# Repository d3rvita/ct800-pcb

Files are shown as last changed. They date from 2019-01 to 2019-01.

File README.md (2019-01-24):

# CT800-PCB

In order to become familiar with KiCAD and making something useful at the same time I started this project. The goal was to develop a PCB for the CT800 to ease the build-up. The CT800 is a dedicated chess computer made by Rasmus Althoff. It is very well documented, take a look at its homepage [www.ct800.net](https://www.ct800.net "CT800 Homepage") for detailed info. 

The developed PCB consists entirely of THT components except one SMD transistor, due to better availability of 3.3V logic level devices. Soldering SMD parts isn’t easy especially packages like LQFP64 with 0.5mm pitch, therefore the Olimex board was kept in this design. The CT800 was extended by some interfaces (RS232, Bluetooth, WLAN) for future use. The power supply was amended a bit too.

CAD files of appropriate panels for housings are also included in this project. There are two versions:

* the Spartan one consists of front and back panel which are bolted to the PCB by studs
* the Classic one consists of just a front panel for the housing used by Rasmus (Axxatronic BIM1006-BLK/PG or BIM1006-GY/PG)

These panels are intended to be transparent, hence there are no holes for display and LEDs. Due to transparency there is no need for additional button labels.

## Project Data

* __CT800_PCB__ directory contains the KiCAD project including project specific libs and footprints as well gerber files for PCB production

* __CT800_PANEL__ directory contains panels (in KiCAD layout and SVG formats) for different housings

* __gen_panel_acrylic.py__ Python script for generating panel layouts from PCB layout

* __bom.txt__ lists the bill of material, mounting material for panels not included (M3x8mm / M3x25mm studs, washers, bolts...)

## Power Supply

Depending on assembly the CT800 can be powered by different sources: 

* by a 5V source on the USB-A connector 
* by power adopter or external battery on the barrel jack
	* 8-12VDC if the 7805 voltage regulator is used 
	* 4-12VDC if the Pololu S9V11F5 is used
* by internal battery if a switch is used

The USB-B connector on the Olimex board is not intended for powering the CT800 but for USB devices like a sensor chessboard. So __don’t feed the CT800 via USB-B connector.__

__Don’t provide power from multiple sources simultaneously to the CT800 in general. This could lead to side effects or even damage!__

In order to feed the CT800 by low voltage power supply down to 4VDC  (e.g. battery) equip the PCB with the Pololu S9V11F5 voltage regulator (or similar 5V buck/boost converter) instead of the 7805. In this context replacing the 1N4007 diode by a Schottky type (e.g. 1N5818, SB130) is recommended for higher efficiency.

The CT800 firmware provides voltage monitoring for four NiMH (or alkaline) cells connected in serial, in order to protect rechargeable batteries from deep discharge. This only makes sense in conjunction with the Pololu regulator. Dispense with this monitoring eases the build-up, so omit it unless you really need it. To do so, omit the voltage divider components (R2, R3 and C1), instead connect the R2 pad next to C1 to 3.3V (red wire on ct800_spartan_bottom.jpg).

A power switch is not provided on the PCB but can be connected easily to PWR and USB_SEL pads.

### Operating Without Power Switch

The CT800 is immediately powered by plugging a 5V supply to the USB-A connector or a “wide range” power source to the barrel jack (8-12VDC or 4-12VDC depending on the used 5V regulator).

If battery monitoring is active (thus the Pololu is used), the USB power has to be redirected to 5V regulator’s input via the USB_SEL jumper: disrupt the connection on top side between the upper two pads and short-circuit the lower two. Otherwise powering via USB will result in “low batteries” error message. Because of this redirection the power adopter (or battery) is directly connected to the USB power supply. __Despite the fuses, this easily lead to damage in case two power sources are used simultaneously!__ Therefore use a switch instead or dispense with battery monitoring.

### Operating With Power Switch

Without battery monitoring a 2x3 pin toggle switch is sufficient to switch between USB-A and barrel jack supply. An external battery can still be used on the barrel jack. If internal battery is desired a 1x4 rotary switch is recommended for supply selection. Wire the switch as shown in the picture below, don’t forget to disrupt the red marked traces on the PCB.

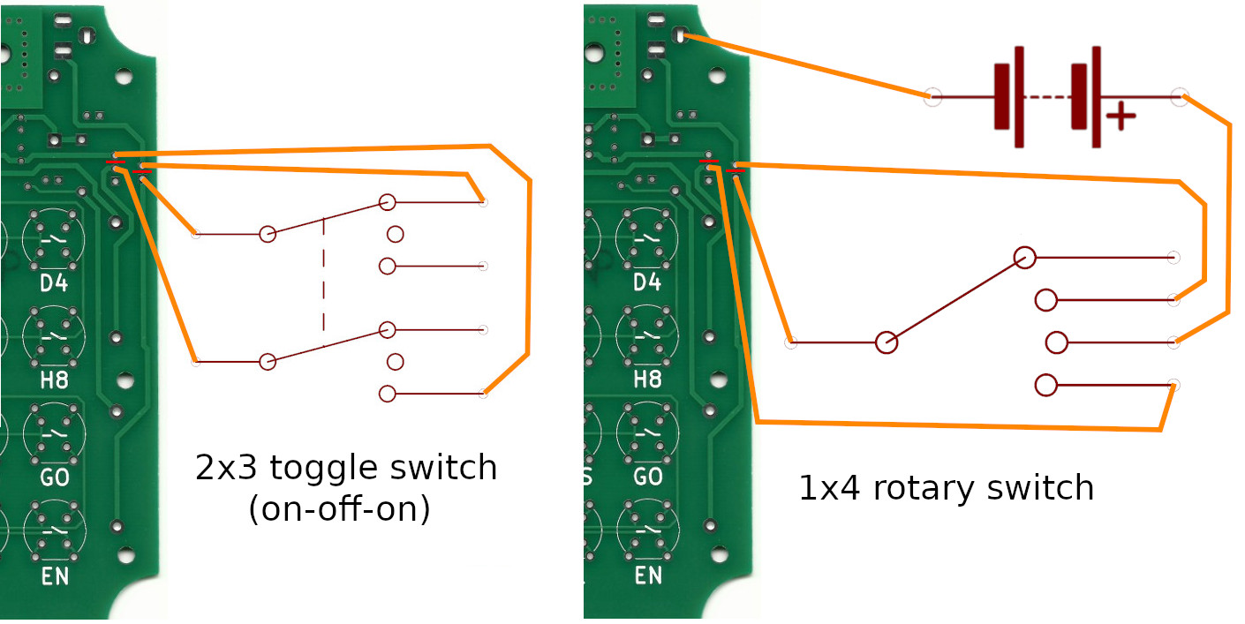
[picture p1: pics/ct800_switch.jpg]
switch


Many other switch configurations are possible. Whatever you choose, ensure power sources are never short circuit!

## PCB Assembly

Read the entire text before starting assembly. Decide what power source you want to use for feeding the CT800 and if you need a power switch or not. Since the ESP-01 is not used yet by the firmware, there is no need for equipping it. This just leads to higher current consumption. It is recommended to place the smallest components first: the SMD transistor, resistors, capacitors and then the remaining parts but the display and Olimex board. Consider the polarity of diodes, LEDs (cathode to rectangular pad = ground) and polarized capacitors. Apply heat paste to the voltage regulator(s) and screw them to the PCB before soldering. If battery monitoring is used, activate the JP3 jumper on top side. Before placing display and Olimex board check the 5V and 3.3V voltages (there are test points on the PCB). __Don’t proceed until these voltages are alright.__ Before soldering the display, screw it to the PCB and adjust the height by putting washers in between. On some displays the polarity of the back light has to be changed. On the back side of the display are jumpers for this purpose, regard the data sheet. __Don’t solder the Olimex board to the PCB, use female header instead.__ For UART communication between µC and ESP-01 the resistor R27 on the Olimex board has to be removed. In order to prevent the gold-cap to be drained in off state, the VBAT jumper on the STM32H405 board has to be disrupted. 

## Schematic

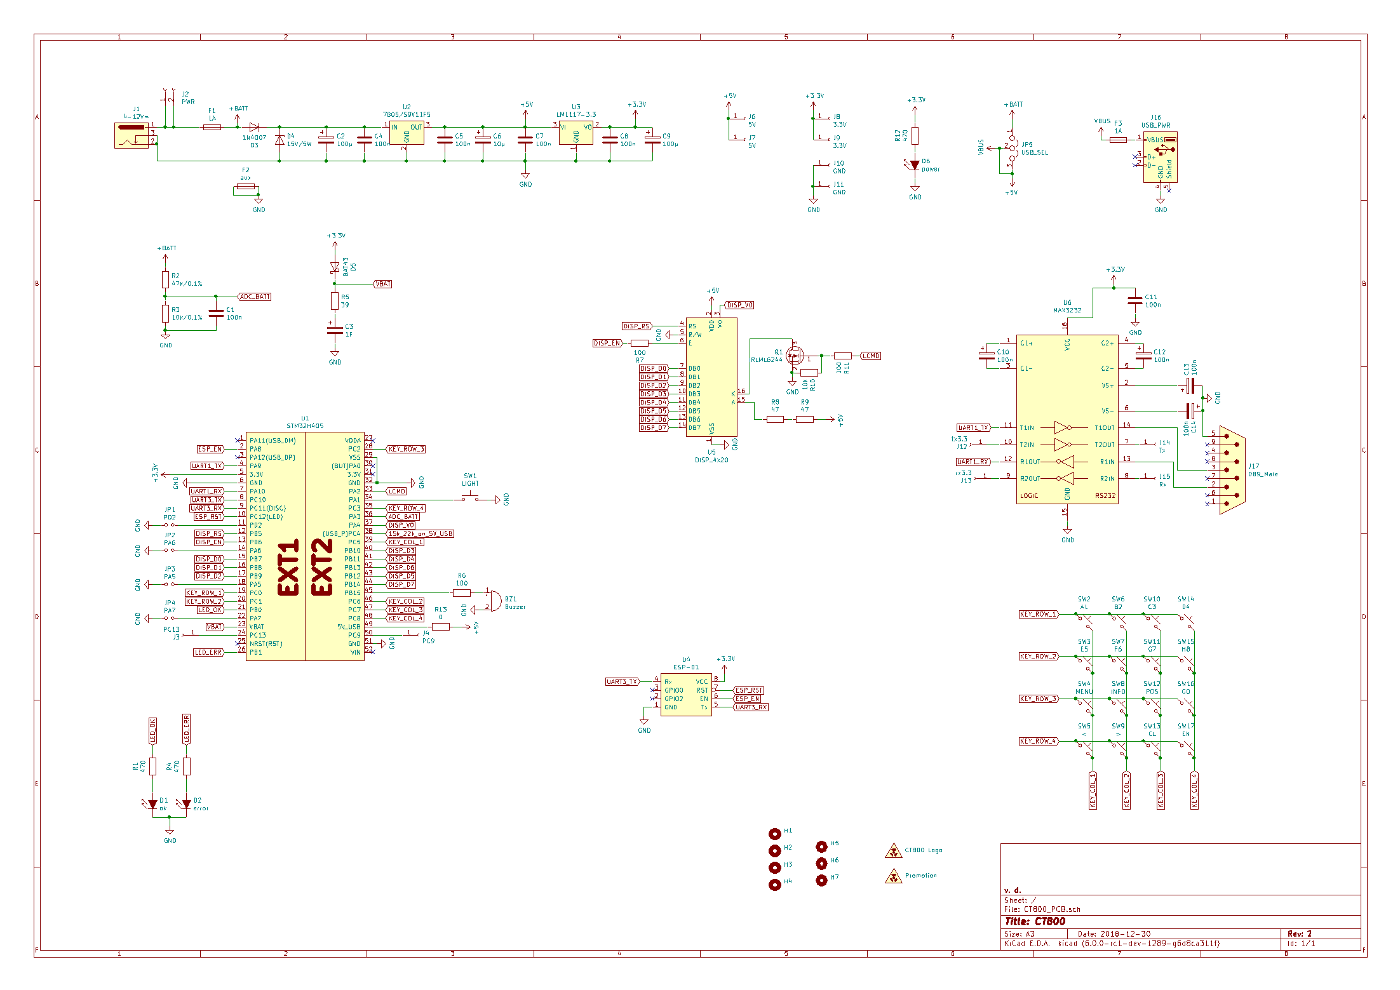
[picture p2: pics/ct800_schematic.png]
schematic


## PCB

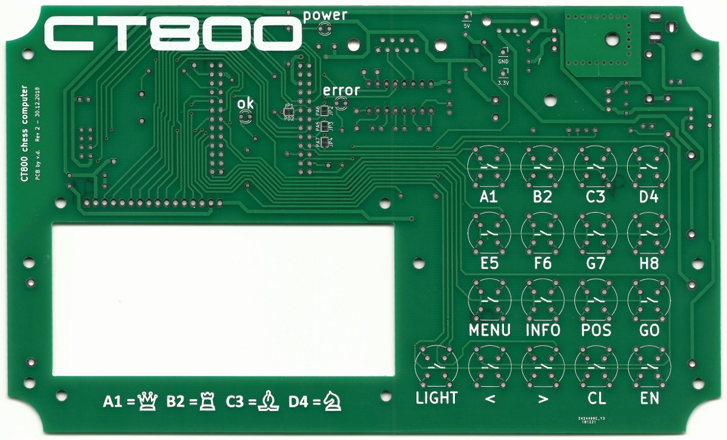
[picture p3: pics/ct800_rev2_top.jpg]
pcb_top


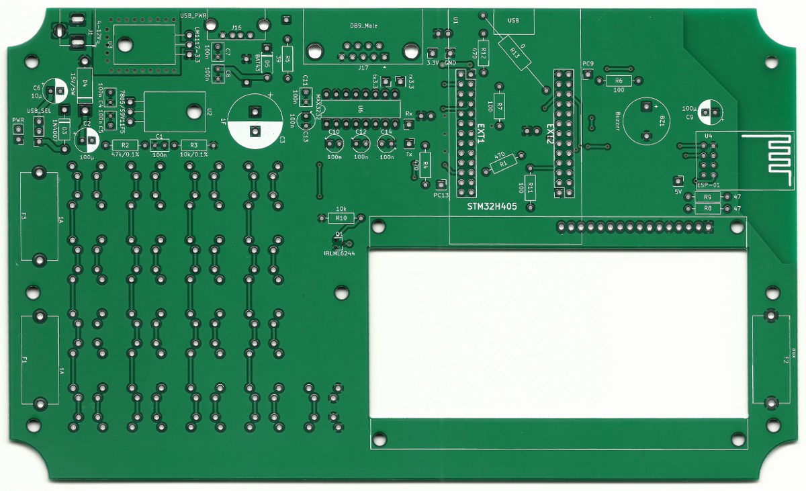
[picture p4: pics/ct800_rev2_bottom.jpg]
pcb_bottom


## Spartan Housing

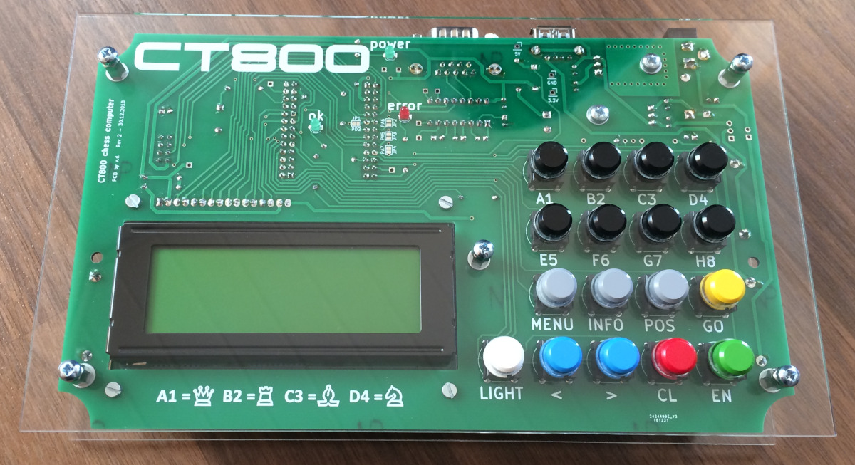
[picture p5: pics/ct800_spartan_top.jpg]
spartan_top


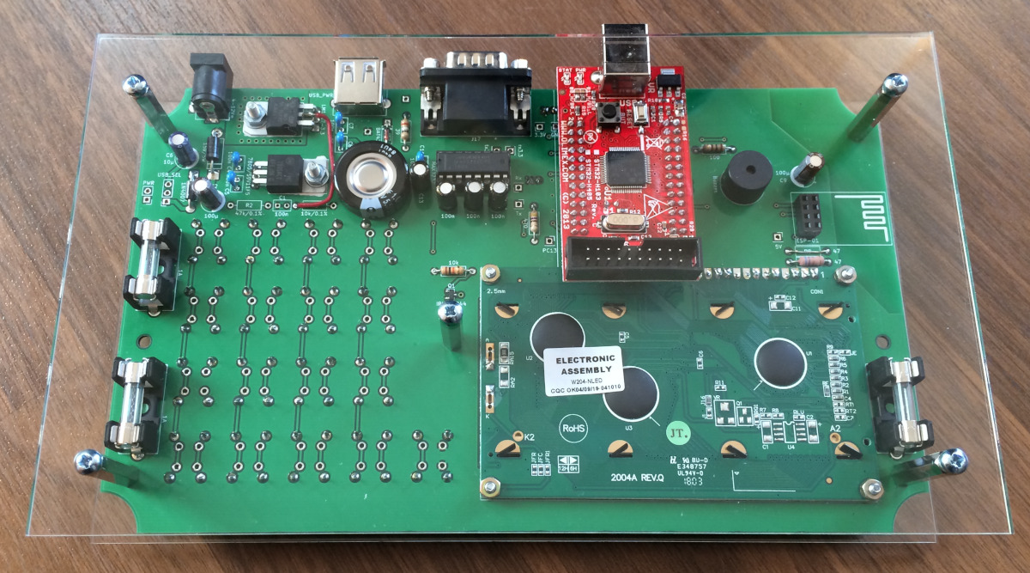
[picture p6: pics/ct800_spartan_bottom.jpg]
spartan_bottom


## Classic Housing

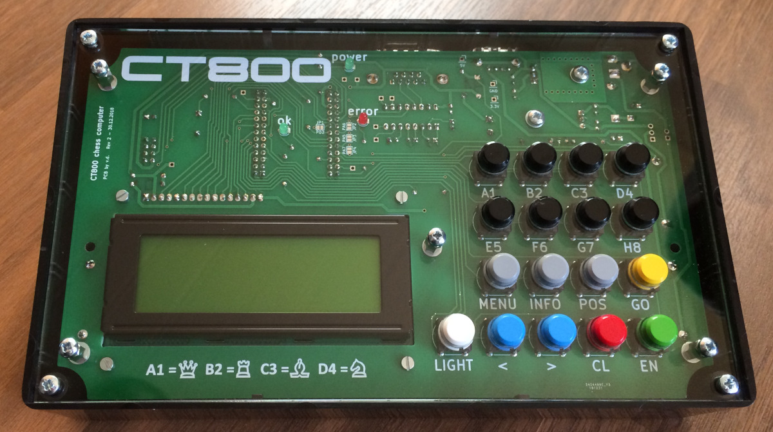
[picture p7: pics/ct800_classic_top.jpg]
classic_top

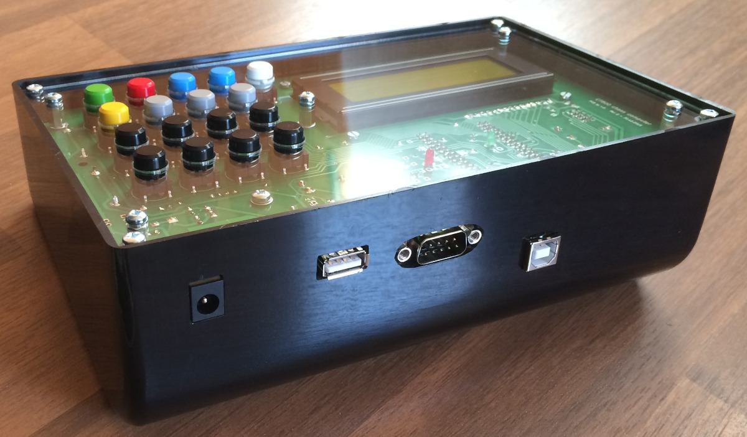
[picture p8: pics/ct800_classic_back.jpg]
classic_back


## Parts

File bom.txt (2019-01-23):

Reference		 Quantity		 Value			 Description
BZ1 				1			"Buzzer"		"Buzzer/Beeper, not a bare piezo element"
C10 C12 C13 C14 	4			"100n/16V"		"Capacitor, D4.5mm P2.50mm"
C2 C9 				2			"100µ/16V"		"Capacitor, D6.3mm P2.50mm"
C3 					1			"1F/5.5V"		"Capacitor, D14.0mm P5.00mm"
C4 C7 C5 C11 C8 C1 	6			"100n/16V"		"Capacitor, L4.6mm W3.0mm P2.50mm"
C6 					1			"10µ/16V"		"Capacitor, D6.3mm P2.50mm"
D1 					1			"ok"			"LED D3.0mm green"
D2 					1			"error"			"LED D3.0mm red"
D6 					1			"power"			"LED D3.0mm green"
D3					1			"1N4007"		"Diode DO-41, alternatively a Schottky type"
D4 					1			"15V/5W"		"Diode D_5W"
D5 					1			"BAT43"			"Diode D_A-405"
F1 F2 F3 			2			"1A/fast"		"Fuseholder P22,5mm + Fuse 5x20mm"
J1 					1			"4-12V="		"BarrelJack (5.5mm / 2.1mm, plus inside)"
J16 				1			"USB_PWR"		"USB_A Connector"
J17 				1			"DB9_Male"		"DSUB-9_Male Connector P2.77x2.84mm (Offset_9.90mm_11.32mm)"
Q1 					1			"IRLML6244"		"MOSFET SOT-23"
R10 				1			"10k"			"Resistor 0204"
R13 				1			"0"				"Wire"
R2					1			"47k/0.1%"		"Resistor 0204, for battery monitoring only"
R3					1			"10k/0.1%"		"Resistor 0204, for battery monitoring only"
R4 R1 R12 			3			"470"			"Resistor 0204"
R5 					1			"39"			"Resistor 0204"
R6 R11 R7 			3			"100"			"Resistor 0204"
R9 R8 				2			"47"			"Resistor 0204, values depending on the display back light"
SW1 - SW17			17			"~"				"Switches, MULTIMEC 3FTH9 (10.16x7.62mm) or ITT DT6 (5x5mm)"
U1 					1			"STM32H405"		"Olimex STM32H405 Board, additional: 2pc. 2x13pin female header P2.54mm"
U2 					1			"7805/S9V11F5"	"5V Voltage Regulator TO220"
U3 					1			"LM1117-3.3"	"3.3V Voltage Regulator TO220"
U4 					1			"ESP-01"		"ESP8266 board"
U5					1			"DISP_4x20"		"4x20 Display based on ST7066, additional M2.5 bolts, nuts and washers for mounting"
U6 					1			"MAX3232"		"DIP-16_W7.62mm, socket recommended"

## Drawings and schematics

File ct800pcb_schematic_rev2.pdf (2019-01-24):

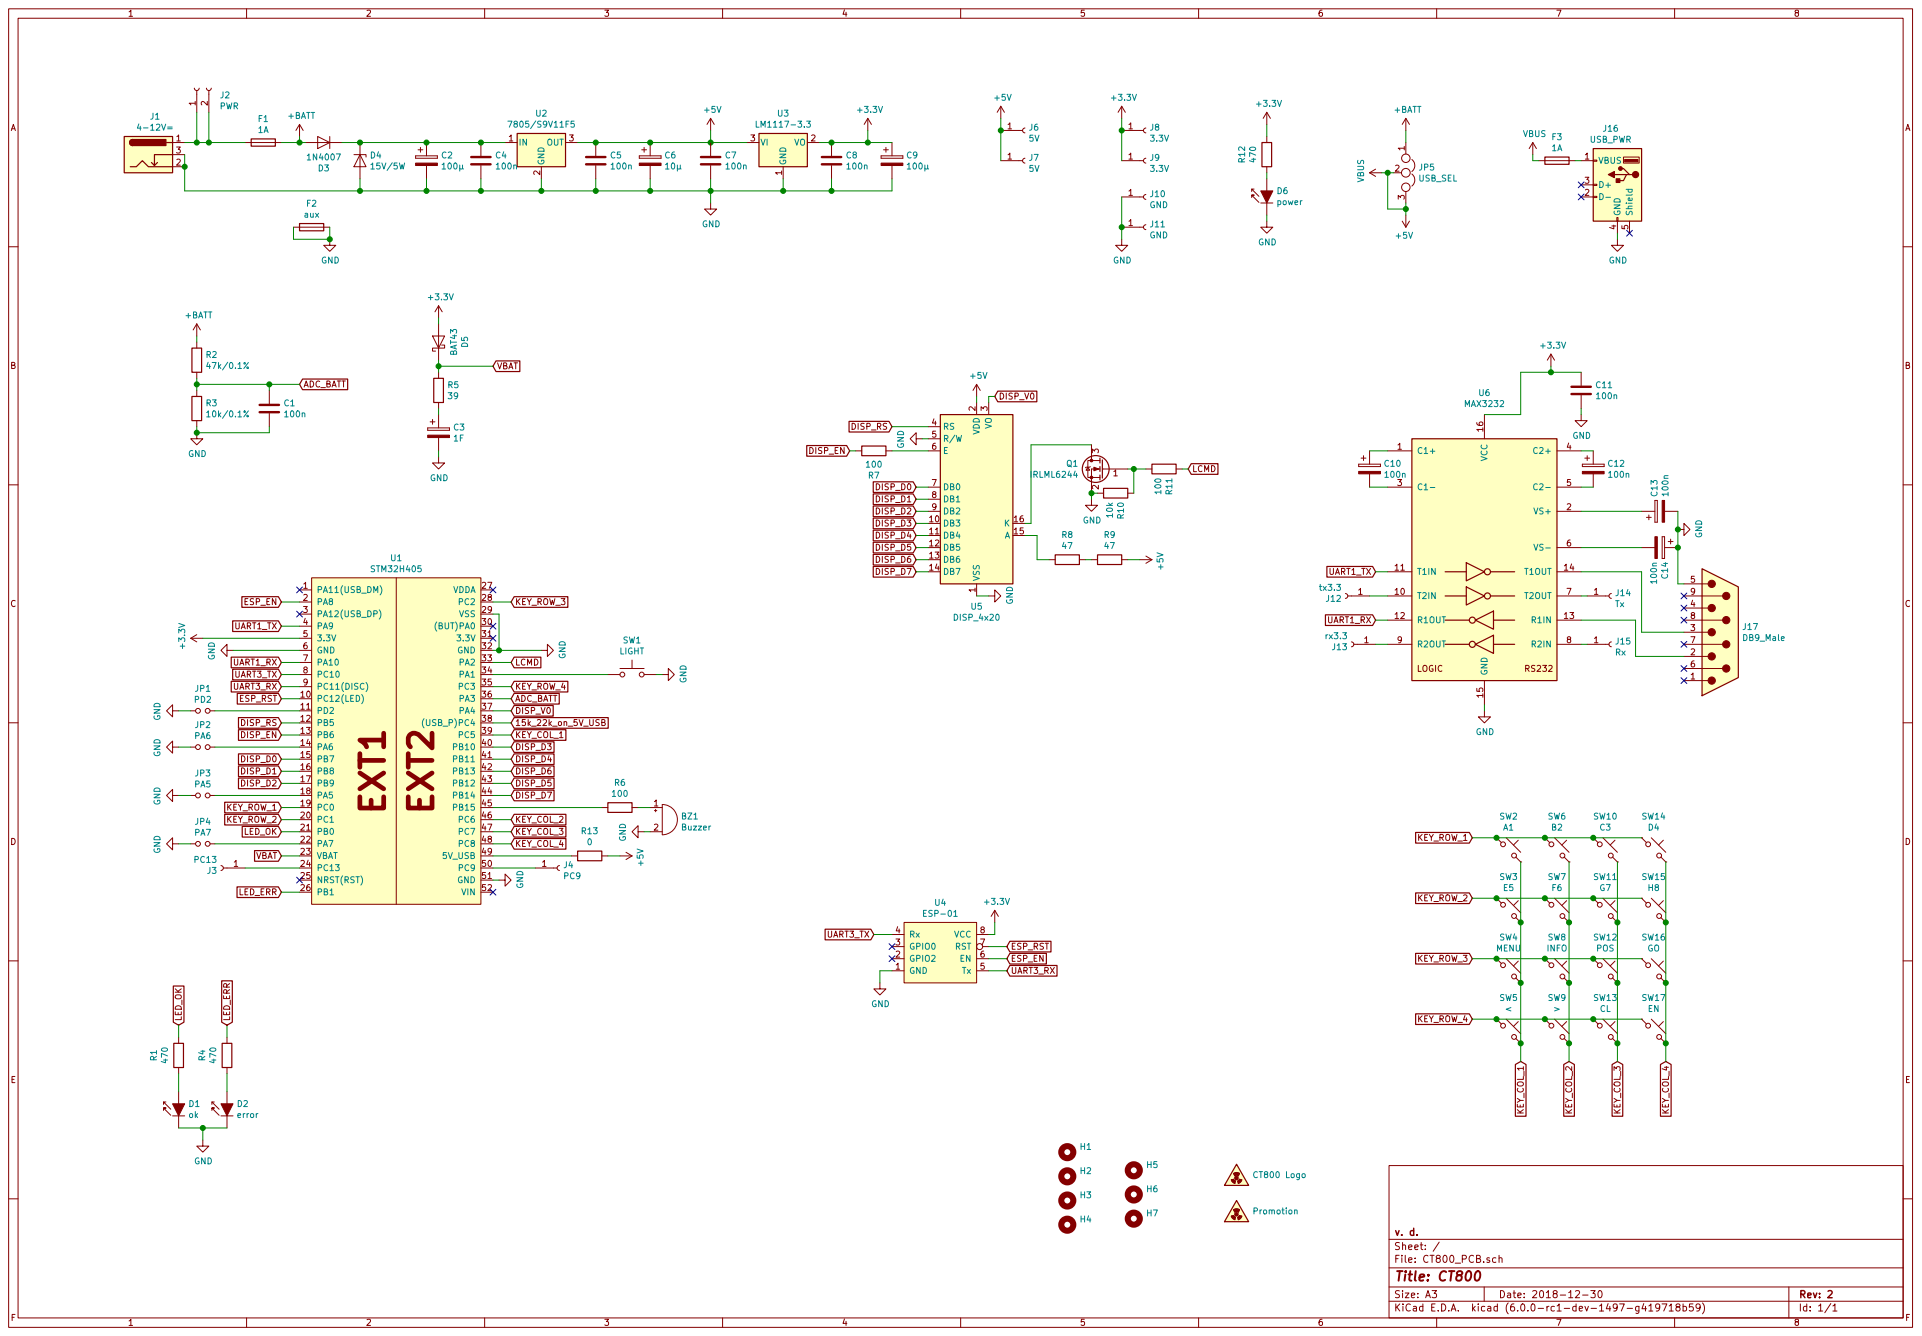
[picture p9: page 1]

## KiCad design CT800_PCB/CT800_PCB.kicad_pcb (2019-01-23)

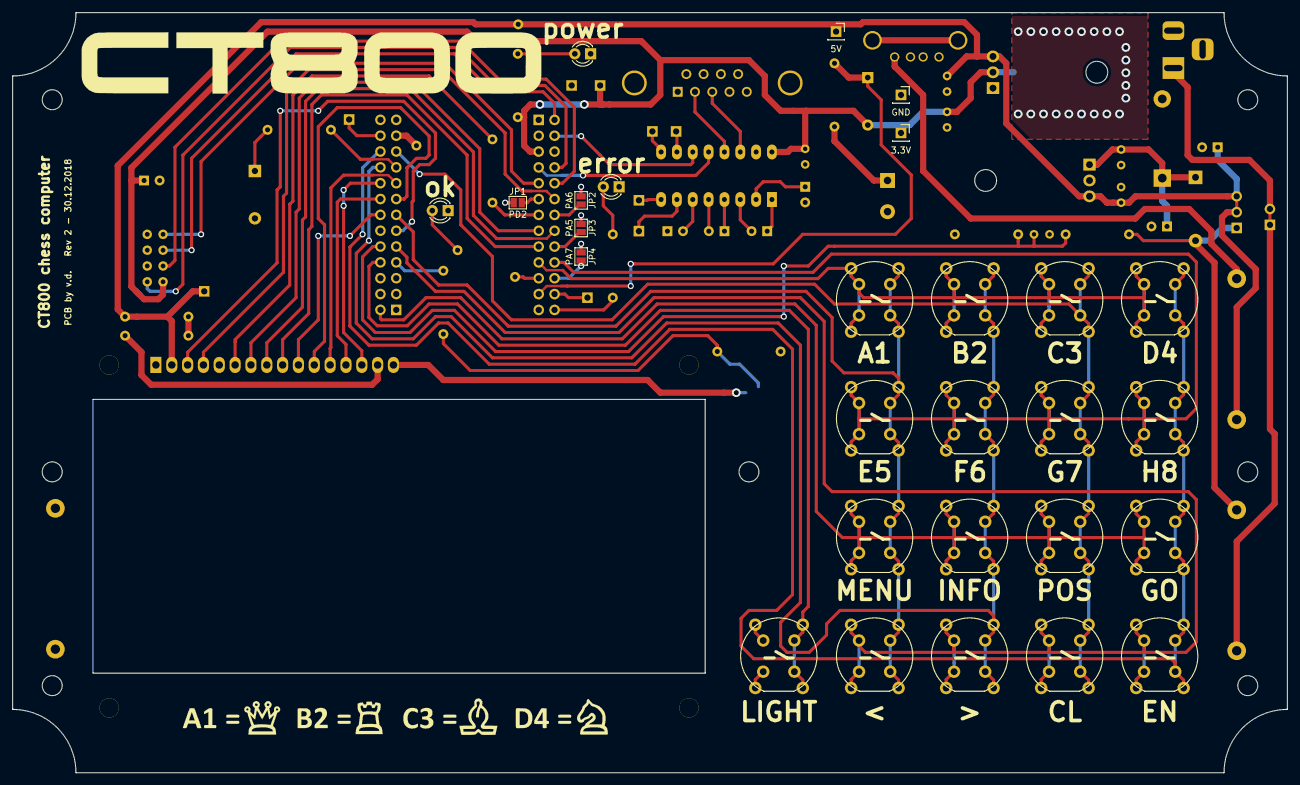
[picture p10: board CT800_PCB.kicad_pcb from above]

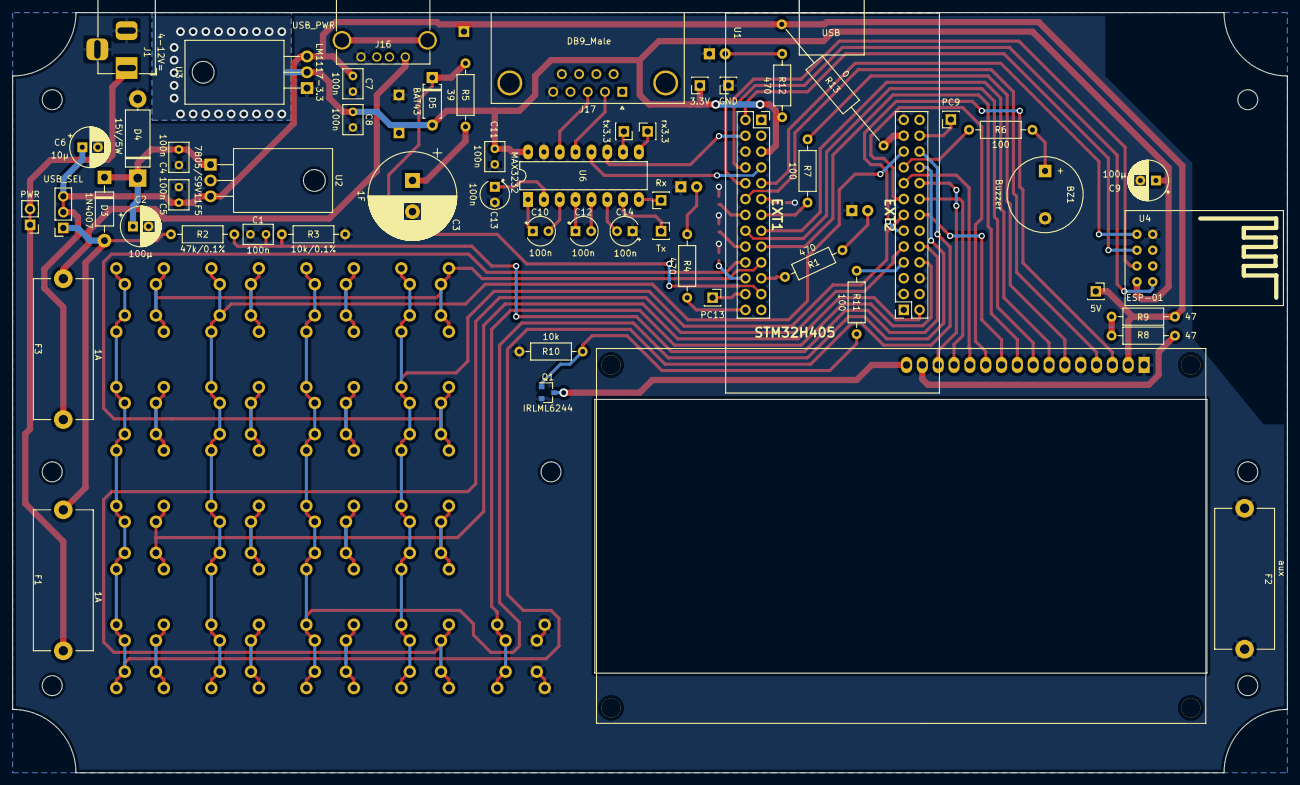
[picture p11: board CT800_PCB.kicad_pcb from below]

Board: 2 copper layers, 204.5 x 121.9 mm, 91 parts (54 on the bottom side), 68 nets.

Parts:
BZ1: Buzzer; Buzzer_12x9.5RM7.6
C1, C4, C5, C7, C8, C11: 100n; C_Rect_L4.6mm_W3.0mm_P2.50mm_MKS02_FKP02
C2, C9: 100µ; CP_Radial_D6.3mm_P2.50mm
C3: 1F; CP_Radial_D14.0mm_P5.00mm
C6: 10µ; CP_Radial_D6.3mm_P2.50mm
C10, C12, C13, C14: 100n; CP_Radial_Tantal_D4.5mm_P2.50mm
D1: ok; LED_D3.0mm
D2: error; LED_D3.0mm
D3: 1N4007; D_DO-41_SOD81_P10.16mm_Horizontal
D4: 15V/5W; D_5W_P12.70mm_Horizontal
D5: BAT43; D_A-405_P7.62mm_Horizontal
D6: power; LED_D3.0mm
F1, F3: 1A; Fuseholder_Cylinder-5x20mm_Stelvio-Kontek_PTF78_Horizontal_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
F2: aux; Fuseholder_Cylinder-5x20mm_Stelvio-Kontek_PTF78_Horizontal_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
H1, H2, H3, H4, H5, H6, H7: MountingHole; MountingHole_3.2mm_M3
J1: 4-12V=; BarrelJack_Horizontal
J2: PWR; Pin_Header_Straight_1x02_Pitch2.54mm
J3: PC13; PinSocket_1x01_P2.54mm_Vertical
J4: PC9; PinSocket_1x01_P2.54mm_Vertical
J6, J7: 5V; PinSocket_1x01_P2.54mm_Vertical
J8, J9: 3.3V; PinSocket_1x01_P2.54mm_Vertical
J10, J11: GND; PinSocket_1x01_P2.54mm_Vertical
J12: tx3.3; PinSocket_1x01_P2.54mm_Vertical
J13: rx3.3; PinSocket_1x01_P2.54mm_Vertical
J14: Tx; PinSocket_1x01_P2.54mm_Vertical
J15: Rx; PinSocket_1x01_P2.54mm_Vertical
J16: USB_PWR; USB_A
J17: DB9_Male; DSUB-9_Male_Horizontal_P2.77x2.84mm_EdgePinOffset9.90mm_Hou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
JP1: PD2; SolderJumper-2_P1.3mm_Open_Pad1.0x1.5mm
JP2: PA6; SolderJumper-2_P1.3mm_Open_Pad1.0x1.5mm
JP3: PA5; SolderJumper-2_P1.3mm_Open_Pad1.0x1.5mm
JP4: PA7; SolderJumper-2_P1.3mm_Open_Pad1.0x1.5mm
JP5: USB_SEL; PinSocket_1x03_P2.54mm_Vertical
Q1: IRLML6244; SOT-23
R1, R4, R12: 470; R_Axial_DIN0207_L6.3mm_D2.5mm_P10.16mm_Horizontal
R2: 47k/0.1%; R_Axial_DIN0207_L6.3mm_D2.5mm_P10.16mm_Horizontal
R3: 10k/0.1%; R_Axial_DIN0207_L6.3mm_D2.5mm_P10.16mm_Horizontal
R5: 39; R_Axial_DIN0207_L6.3mm_D2.5mm_P10.16mm_Horizontal
R6, R7, R11: 100; R_Axial_DIN0207_L6.3mm_D2.5mm_P10.16mm_Horizontal
R8, R9: 47; R_Axial_DIN0207_L6.3mm_D2.5mm_P10.16mm_Horizontal
R10: 10k; R_Axial_DIN0207_L6.3mm_D2.5mm_P10.16mm_Horizontal
R13: 0; R_Axial_DIN0309_L9.0mm_D3.2mm_P25.40mm_Horizontal
SW1: LIGHT; D6_3FTH
SW2: A1; D6_3FTH
SW3: E5; D6_3FTH
SW4: MENU; D6_3FTH
SW5: <; D6_3FTH
SW6: B2; D6_3FTH
SW7: F6; D6_3FTH
SW8: INFO; D6_3FTH
SW9: >; D6_3FTH
SW10: C3; D6_3FTH
SW11: G7; D6_3FTH
SW12: POS; D6_3FTH
SW13: CL; D6_3FTH
SW14: D4; D6_3FTH
SW15: H8; D6_3FTH
SW16: GO; D6_3FTH
SW17: EN; D6_3FTH
SYM1: CT800 Logo; ct800
SYM2: Promotion; promotion
U1: STM32H405; Olimex_STM32H405
U2: 7805/S9V11F5; TO-220-3_Horizontal_TabDown
U3: LM1117-3.3; TO-220-3_Horizontal_TabDown
U4: ESP-01
U5: DISP_4x20; LCD04x20BL
U6: MAX3232; DIP-16_W7.62mm_LongPads

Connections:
+3V3: C8.1, C9.1, C11.1, D5.2, J8.1, J9.1, R12.2, U1.5, U3.2, U4.8, U6.16
+5V: C5.1, C6.1, C7.1, F3.2, J6.1, J7.1, JP5.2, JP5.3, R9.2, R13.2, U2.3, U3.3, U5.2
+BATT: D3.2, F1.1, JP5.1, R2.1
ADC_BATT: C1.1, R2.2, R3.1, U1.36
DISP_D0: U1.15, U5.7
DISP_D1: U1.16, U5.8
DISP_D2: U1.17, U5.9
DISP_D3: U1.40, U5.10
DISP_D4: U1.41, U5.11
DISP_D5: U1.43, U5.12
DISP_D6: U1.42, U5.13
DISP_D7: U1.44, U5.14
DISP_EN: R7.2, U1.13
DISP_RS: U1.12, U5.4
DISP_V0: U1.37, U5.3
ESP_EN: U1.2, U4.6
ESP_RST: U1.10, U4.7
GND: BZ1.2, C1.2, C2.2, C3.2, C4.2, C5.2, C6.2, C7.2, C8.2, C9.2, C11.2, C13.2, C14.1, D1.1, D2.1, D4.2, D6.1, F2.1, F2.2, J1.2, J1.3, J10.1, J11.1, J16.4, J17.5, JP1.1, JP2.1, JP3.1, JP4.1, Q1.2, R3.2, R10.2, SW1.1, U1.6, U1.29, U1.32, U1.51, U2.2, U3.1, U4.1, U5.1, U5.5, U6.15
KEY_COL_1: SW2.2, SW3.2, SW4.2, SW5.2, U1.39
KEY_COL_2: SW6.2, SW7.2, SW8.2, SW9.2, U1.46
KEY_COL_3: SW10.2, SW11.2, SW12.2, SW13.2, U1.47
KEY_COL_4: SW14.2, SW15.2, SW16.2, SW17.2, U1.48
KEY_ROW_1: SW2.1, SW6.1, SW10.1, SW14.1, U1.19
KEY_ROW_2: SW3.1, SW7.1, SW11.1, SW15.1, U1.20
KEY_ROW_3: SW4.1, SW8.1, SW12.1, SW16.1, U1.28
KEY_ROW_4: SW5.1, SW9.1, SW13.1, SW17.1, U1.35
LCMD: R11.1, U1.33
LED_ERR: R4.2, U1.26
LED_OK: R1.2, U1.21
unnamed: BZ1.1, R6.2
unnamed: C2.1, C4.1, D3.1, D4.1, U2.1
unnamed: C3.1, R5.2
unnamed: C10.1, U6.1
unnamed: C10.2, U6.3
unnamed: C12.1, U6.4
unnamed: C12.2, U6.5
unnamed: C13.1, U6.2
unnamed: C14.2, U6.6
unnamed: D1.2, R1.1
unnamed: D2.2, R4.1
unnamed: D6.2, R12.1
unnamed: F1.2, J1.1, J2.1, J2.2
unnamed: F3.1, J16.1
unnamed: J3.1, U1.24
unnamed: J4.1, U1.50
unnamed: J12.1, U6.10
unnamed: J13.1, U6.9
unnamed: J14.1, U6.7
unnamed: J15.1, U6.8
unnamed: J17.2, U6.13
unnamed: J17.3, U6.14
unnamed: JP1.2, U1.11
unnamed: JP2.2, U1.14
unnamed: JP3.2, U1.18
unnamed: JP4.2, U1.22
unnamed: Q1.1, R10.1, R11.2
unnamed: Q1.3, U5.16
unnamed: R6.1, U1.45
unnamed: R7.1, U5.6
unnamed: R8.1, U5.15
unnamed: R8.2, R9.1
unnamed: R13.1, U1.49
unnamed: SW1.2, U1.34
UART1_RX: U1.7, U6.12
UART1_TX: U1.4, U6.11
UART3_RX: U1.9, U4.5
UART3_TX: U1.8, U4.4
VBAT: D5.1, R5.1, U1.23

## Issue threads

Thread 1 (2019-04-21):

For Sale?

ScallyBag, 2019-04-21:
Hi,

Are you selling a complete unit in the Classic housing?

Al.

Xsvech, 2021-02-28:
НПК Сергея Маузера - производитель оборудования для свечей
xsvechi.com

Оборудование для производства свечей от НПК Сергея Маузера. ... Выгода для покупателей свечного оборудования НПК Сергея Маузера. Читать ещё
Россия, Иваново, Старокурьяновская улица, 19
+7 (952) 430-66-49
